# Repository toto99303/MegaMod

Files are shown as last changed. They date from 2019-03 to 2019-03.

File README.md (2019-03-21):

# MegaMod
These are the three versions of MegaMod PCB for Sega Genesis.
Created with Eagle PCB.

v1 - uses PIC16F630 (https://vmod.wordpress.com/megamod-v1-0/)  
v2 - uses Atmega328P with internal oscillator (https://vmod.wordpress.com/megamod-v2-0/)  
v3 - uses Atmega328P with internal oscillator + THS video amp (https://vmod.wordpress.com/megamod-v3-0/)

PIC code used in v1: https://github.com/sebknzl/saturnmod

The Arduino code for v2 and v3 was based on this project:
https://github.com/SukkoPera/MegaDrivePlusPlus

Due to some bugs related to the Atmega328P internal oscillator the Arduino code was never finished.

The audio part of the mod is based on the circuits posted in this forum by Ace (MegaAmp):
http://www.sega-16.com/forum/showthread.php?26568-Introducing-the-Mega-Amp-The-universal-Genesis-audio-circuit

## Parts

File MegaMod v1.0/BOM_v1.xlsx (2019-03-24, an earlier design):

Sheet: MegaMod v1
Discrete YM2612 - MD1 - All except VA7, MD2 - VA2, VA2.3 |  |  |  |  | ASIC YM3438, MD1 - VA7, MD2 - VA0, VA1, VA1.8, VA3
Name | Part | Count | Package | Remark | Name | Part | Count | Package | Remark
PCB | Board | 1 |  |  | PCB | Board | 1
U1 | TL074CD | 1 | SOIC127P600X175-14N |  | U1 | TL074CD | 1 | SOIC127P600X175-14N
U2 | PIC16F630-I/SL | 1 | SOIC127P600X175-14N |  | U2 | PIC16F630-I/SL | 1 | SOIC127P600X175-14N
S1 | DPDT Swtich | 1 | AYZ0202 |  | S1 | DPDT Swtich | 1 | AYZ0202
C1 | 100nF | 1 | 1210 |  | C1 | 100nF | 1 | 1210
C2 | 100uF | 1 | 1206 |  | C2 | 100uF | 1 | 1206
C3-C5 | 220uF | 3 | CAPAE830X650N |  | C3-C5 | 220uF | 3 | CAPAE830X650N
C6,C9 | 47pF | 2 | 1206 |  | C6,C9 | 47pF | 2 | 1206
C7-C8 | 270pF | 2 | 1206 |  | C7-C8 | 270pF | 2 | 1206
C10, C17 | 10uF | 2 | 1206 |  | C10, C17 | 10uF | 2 | 1206
C11-C16 | 1uF | 6 | 1206 |  | C11-C16 | 1uF | 6 | 1206
R1 -R2 | 220 | 2 | 1206 |  | R1 -R2 | 220 | 2 | 1206
R3 -R4 | 330 | 2 | 1206 |  | R3 -R4 | 330 | 2 | 1206
R5 - R6 | 160k | 2 | 1206 |  | R5 - R6 | 160k | 2 | 1206
R7 | 510 | 1 | 1206 |  | R7 | 510 | 1 | 1206
R8 | 750 | 1 | 1206 |  | R8 | 750 | 1 | 1206
R9, R22 | 2k2 | 0 | 1206 | Optional if fitting 2612 on asic board | R9, R22 | 2k2 | 0 | 1206
R10, R23 | 6k2 | 2 | 1206 |  | R10, R23 | 51k | 2 | 1206
R11, R13, R18, R20 | 75 | 4 | 1206 |  | R11, R13, R18, R20 | 75 | 4 | 1206
R12, R14, R19, R21 | 130k | 4 | 1206 |  | R12, R14, R19, R21 | 130k | 4 | 1206
R15 | 1k3 | 1 | 1206 | 330 for MD2 VA2, VA2.3 | R15 | 1k3 | 1 | 1206
R16 -R17 | 100k | 2 | 1206 |  | R16 -R17 | 100k | 2 | 1206
GOAC YM3438 - MD2 - VA4, MD3 - VA1,VA2
Name | Part | Count | Package | Remark
PCB | Board | 1
U1 | TL074CD | 1 | SOIC127P600X175-14N
U2 | PIC16F630-I/SL | 1 | SOIC127P600X175-14N
S1 | DPDT Swtich | 1 | AYZ0202
C1 | 100nF | 1 | 1210
C2 | 100uF | 1 | 1206
C3-C5 | 220uF | 3 | CAPAE830X650N
C6,C9 | 47pF | 2 | 1206
C7-C8 | 270pF | 2 | 1206
C10, C17 | 10uF | 2 | 1206
C11-C16 | 1uF | 6 | 1206
R1 -R2 | 220 | 2 | 1206
R3 -R4 | 330 | 2 | 1206
R5 - R6 | 160k | 2 | 1206
R7 | 510 | 1 | 1206
R8 | 750 | 1 | 1206
R9, R22 | 2k2 | 0 | 1206
R10, R23 | 39k | 2 | 1206
R11, R13, R18, R20 | 75 | 4 | 1206
R12, R14, R19, R21 | 130k | 4 | 1206
R15 | 2k2 | 1 | 1206
R16 -R17 | 75k | 2 | 1206

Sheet: V2 or V3
Mega Drive 1
 | Language | Video Mode
16F630 output leg | 9 | 12
Connects to | JP 1/2 | JP 3/4 | Sega CD BIOS
 |  |  |  | PIC 8 /Eprom 38 | PIC 10 /Eprom 39
EUR | 1 | 0 | EUR | 0 | 1
JPN | 0 | 1 | JPN | 1 | 0
USA | 1 | 1 | USA | 0 | 0
Final pinout | AVR pin | Arduino pin
RESET IN | PC3 | A3
RESET OUT | PC2 | A2
VIDEO MODE | PB0 | 8
LANGUAGE | PB4 | 12(MISO)
LED R | PB1 | 9
LED G | PB2 | 10
LED B | PB3 | 11
AUDIO MODE | PD7 | 7
CD EPROM pin 38 | PB6 | N/A
CD EPROM pin 39 | PB7 | N/A
PAD PIN 1 | PC0 | A0
PAD PIN 2 | PC1 | A1
PAD PIN 3 | PD3 | 3
PAD PIN 4 | PD4 | 4
PAD PIN 6 | PD5 | 5
PAD PIN 7 | PD2 | 2
PAD PIN 9 | PD6 | 6
INTERNAL LED | PB5 | 13

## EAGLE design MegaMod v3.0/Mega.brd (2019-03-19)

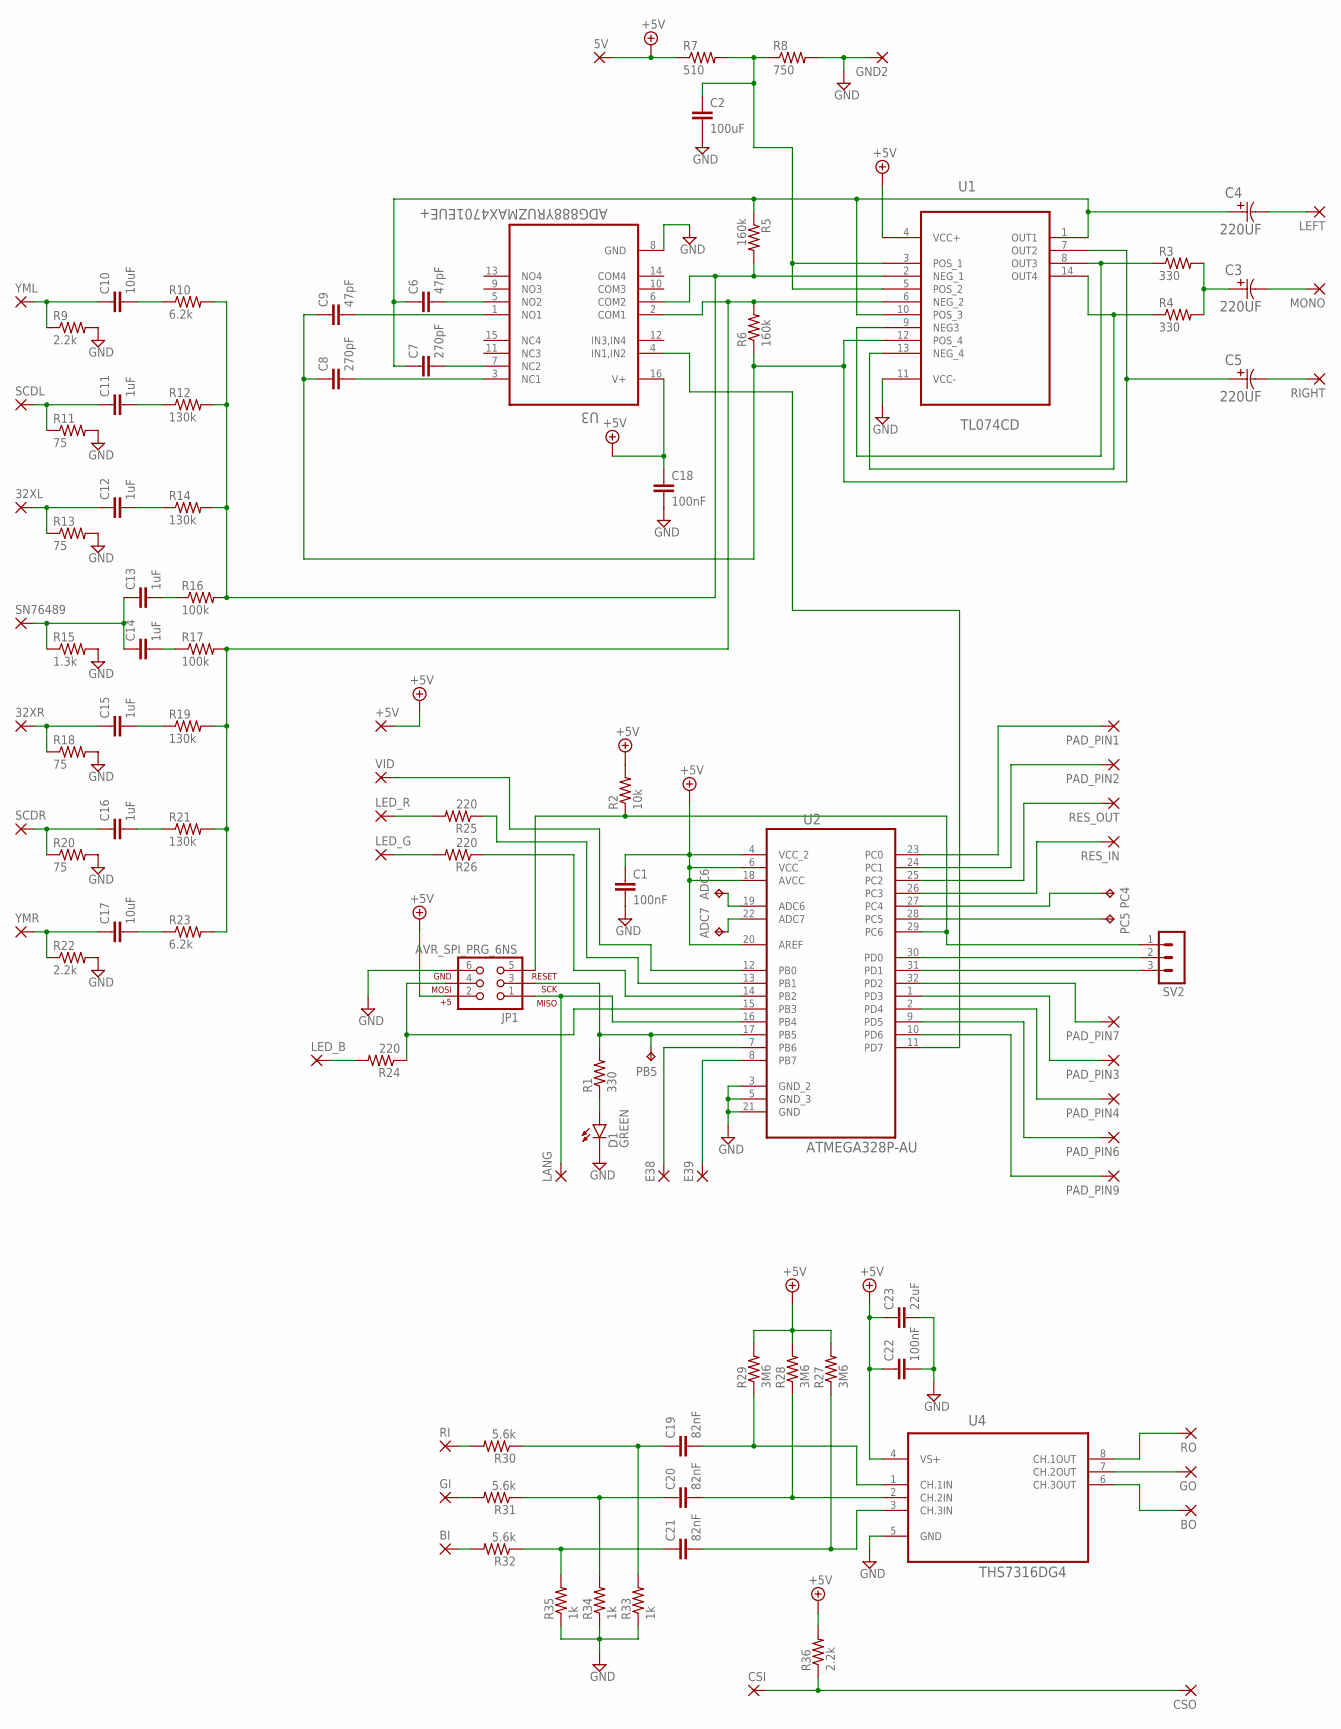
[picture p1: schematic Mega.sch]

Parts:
5V, 32XL, 32XR: SMD2; SMD1,27-2,54
+5V: SMD2; SMD1,27-2,54
ADC6, ADC7: TPB1,27; B1,27
BI: SMD2; SMD1,27-2,54
BO: SMD2; SMD1,27-2,54
C1, C18, C22: 100nF; 0805
C2: 100uF; 1206
C3, C4, C5: 220UF; CAPAE830X650N; TOLERANCE 20 %
C6, C9: 47pF; 0805
C7, C8: 270pF; 0805
C10, C17: 10uF; 0805
C11, C12, C13, C14, C15, C16: 1uF; 0805
C19, C20, C21: 82nF; 0805
C23: 22uF; 0805
CSI: SMD2; SMD1,27-2,54
CSO: SMD2; SMD1,27-2,54
D1: GREEN; LED-1206
E38, E39: SMD2; SMD1,27-2,54
GI: SMD2; SMD1,27-2,54
GND2: SMD2; SMD1,27-2,54
GO: SMD2; SMD1,27-2,54
JP1: AVR_SPI_PRG_6NS; 2X3-NS
LANG: SMD2; SMD1,27-2,54
LED_B: SMD2; SMD1,27-2,54
LED_G: SMD2; SMD1,27-2,54
LED_R: SMD2; SMD1,27-2,54
LEFT: SMD2; SMD1,27-2,54
MONO: SMD2; SMD1,27-2,54
PAD_PIN1, PAD_PIN2, PAD_PIN3, PAD_PIN4, PAD_PIN6, PAD_PIN7, PAD_PIN9: SMD2; SMD1,27-2,54
PB5: TPB1,27; B1,27
PC4, PC5: TPB1,27; B1,27
R1, R3, R4: 330; 0805
R2: 10k; 0805
R5, R6: 160k; 0805
R7: 510; 0805
R8: 750; 0805
R9, R22, R36: 2.2k; 0805
R10, R23: 6.2k; 0805
R11, R13, R18, R20: 75; 0805
R12, R14, R19, R21: 130k; 0805
R15: 1.3k; 0805
R16, R17: 100k; 0805
R24, R25, R26: 220; 0805
R27, R28, R29: 3M6; 0805
R30, R31, R32: 5.6k; 0805
R33, R34, R35: 1k; 0805
RES_IN: SMD2; SMD1,27-2,54
RES_OUT: SMD2; SMD1,27-2,54
RI: SMD2; SMD1,27-2,54
RIGHT: SMD2; SMD1,27-2,54
RO: SMD2; SMD1,27-2,54
SCDL: SMD2; SMD1,27-2,54
SCDR: SMD2; SMD1,27-2,54
SN76489: SMD2; SMD1,27-2,54
SV2: MA03-1
U1: TL074CD; SOIC127P600X175-14N
U2: ATMEGA328P-AU; QFP80P900X900X120-32N
U3: ADG888YRUZMAX4701EUE+; SOP65P640X120-16N
U4: THS7316DG4; SOIC127P600X175-8N
VID: SMD2; SMD1,27-2,54
YML: SMD2; SMD1,27-2,54
YMR: SMD2; SMD1,27-2,54

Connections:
+5V: 5V.1, +5V.1, C1.1, C18.1, C22.1, C23.1, JP1.2, R2.2, R7.1, R27.2, R28.2, R29.2, R36.2, U1.4 (VCC+), U2.4 (VCC_2), U2.6 (VCC), U2.18 (AVCC), U2.20 (AREF), U3.16 (V+), U4.4 (VS+)
GND: C1.2, C2.2, C18.2, C22.2, C23.2, D1.C, GND2.1, JP1.6, R8.2, R9.2, R11.2, R13.2, R15.2, R18.2, R20.2, R22.2, R33.1, R34.1, R35.1, U1.11 (VCC-), U2.3 (GND_2), U2.5 (GND_3), U2.21 (GND), U3.8 (GND), U4.5 (GND)
unnamed: D1.A, R1.1
unnamed: JP1.3, PB5.TP, R1.2, U2.17 (PB5)
unnamed: JP1.5, R2.1, SV2.1, U2.29 (PC6)
unnamed: JP1.1, LANG.1, U2.16 (PB4)
unnamed: JP1.4, R24.1, U2.15 (PB3)
unnamed: LED_R.1, R25.2
unnamed: LED_G.1, R26.2
unnamed: R3.1, U1.8 (OUT3), U1.9 (NEG3)
unnamed: PC4.TP, U2.27 (PC4)
unnamed: PC5.TP, U2.28 (PC5)
unnamed: R4.1, U1.13 (NEG_4), U1.14 (OUT4)
unnamed: C3.1, R3.2, R4.2
unnamed: C3.2, MONO.1
unnamed: C4.2, LEFT.1
unnamed: RES_IN.1, U2.26 (PC3)
unnamed: C4.1, C6.1, C7.1, R5.1, U1.1 (OUT1), U1.10 (POS_3)
unnamed: C5.1, C8.1, C9.1, R6.1, U1.7 (OUT2), U1.12 (POS_4)
unnamed: C5.2, RIGHT.1
unnamed: R6.2, R17.2, R19.2, R21.2, R23.2, U1.6 (NEG_2), U3.2 (COM1)
unnamed: C6.2, U3.5 (NO2)
unnamed: C8.2, U3.3 (NC1)
unnamed: C7.2, U3.7 (NC2)
unnamed: C9.2, U3.1 (NO1)
unnamed: C10.1, R9.1, YML.1
unnamed: C2.1, R7.2, R8.1, U1.3 (POS_1), U1.5 (POS_2)
unnamed: C10.2, R10.1
unnamed: C11.1, R11.1, SCDL.1
unnamed: C11.2, R12.1
unnamed: 32XL.1, C12.1, R13.1
unnamed: C12.2, R14.1
unnamed: C13.1, C14.1, R15.1, SN76489.1
unnamed: C13.2, R16.1
unnamed: C17.1, R22.1, YMR.1
unnamed: C14.2, R17.1
unnamed: 32XR.1, C15.1, R18.1
unnamed: C15.2, R19.1
unnamed: C16.1, R20.1, SCDR.1
unnamed: C16.2, R21.1
unnamed: C17.2, R23.1
unnamed: R5.2, R10.2, R12.2, R14.2, R16.2, U1.2 (NEG_1), U3.6 (COM2)
unnamed: PAD_PIN2.1, U2.24 (PC1)
unnamed: SV2.3, U2.31 (PD1)
unnamed: SV2.2, U2.30 (PD0)
unnamed: PAD_PIN7.1, U2.32 (PD2)
unnamed: PAD_PIN3.1, U2.1 (PD3)
unnamed: PAD_PIN4.1, U2.2 (PD4)
unnamed: PAD_PIN6.1, U2.9 (PD5)
unnamed: PAD_PIN9.1, U2.10 (PD6)
unnamed: LED_B.1, R24.2
unnamed: R26.1, U2.14 (PB2)
unnamed: R25.1, U2.13 (PB1)
unnamed: U2.12 (PB0), VID.1
unnamed: E38.1, U2.7 (PB6)
unnamed: E39.1, U2.8 (PB7)
unnamed: U2.11 (PD7), U3.4 (IN1,IN2)
unnamed: C20.2, R28.1, U4.2 (CH.2IN)
unnamed: C19.2, R29.1, U4.1 (CH.1IN)
unnamed: C21.2, R27.1, U4.3 (CH.3IN)
unnamed: C19.1, R30.1, R33.2
unnamed: C20.1, R31.1, R34.2
unnamed: C21.1, R32.1, R35.2
unnamed: BI.1, R32.2
unnamed: GI.1, R31.2
unnamed: R30.2, RI.1
unnamed: CSI.1, CSO.1, R36.1
unnamed: GO.1, U4.7 (CH.2OUT)
unnamed: RO.1, U4.8 (CH.1OUT)
unnamed: BO.1, U4.6 (CH.3OUT)
unnamed: RES_OUT.1, U2.25 (PC2)
unnamed: PAD_PIN1.1, U2.23 (PC0)
unnamed: ADC7.TP, U2.22 (ADC7)
unnamed: ADC6.TP, U2.19 (ADC6)

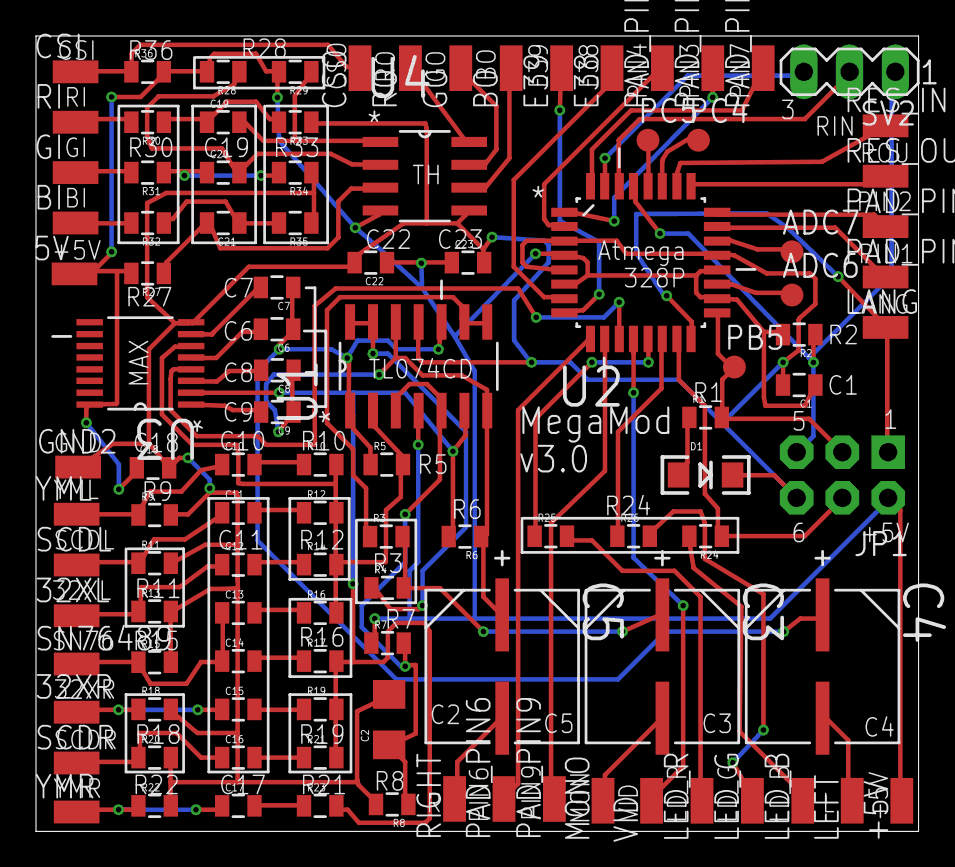
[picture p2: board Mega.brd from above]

Board: 2 copper layers, 49.0 x 44.2 mm, 108 parts (0 on the bottom side), 74 nets.

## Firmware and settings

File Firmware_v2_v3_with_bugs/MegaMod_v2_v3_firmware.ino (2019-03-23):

#include <Arduino.h>

volatile static byte pad_status;
         int i = 0;

#define ARDUINO328

#define RESET_IN_PIN A3
#define RESET_OUT_PIN A2
#define VIDEOMODE_PIN 8 //A4
#define LANGUAGE_PIN MISO //A5
#define MODE_LED_R_PIN 9
#define MODE_LED_G_PIN 10
#define MODE_LED_B_PIN 11
#define AUDIO_MODE_PIN 7
#define PAD_LED_PIN LED_BUILTIN
#define ENABLE_SERIAL_DEBUG
//#define FORCE_RESET_ACTIVE_LEVEL 0


enum PadButton {
  MD_BTN_START = 1 << 7,
  MD_BTN_A =     1 << 6,
  MD_BTN_C =     1 << 5,
  MD_BTN_B =     1 << 4,
  MD_BTN_RIGHT = 1 << 3,
  MD_BTN_LEFT =  1 << 2,
  MD_BTN_DOWN =  1 << 1,
  MD_BTN_UP =    1 << 0
};

/* Button combo that enables the other combos
 *
 * Note: That vertical bar ("pipe") means that the buttons must be pressed
 *       together.
 */

#define TRIGGER_COMBO (MD_BTN_START | MD_BTN_B)
//#define TRIGGER_COMBO (MD_BTN_START)

#define TRIGGER_COMBO2 (MD_BTN_START | MD_BTN_A) //additional combo

/* Button combos to perform other actions. These are to be considered in
 * addition to TRIGGER_COMBO.
 *
 * Note that we cannot detect certain buttons on some platforms
 */
#define RESET_COMBO (MD_BTN_A)



#if defined ARDUINO328

  #define AUDIO_COMBO MD_BTN_UP
  #define EUR_COMBO MD_BTN_DOWN
  #define USA_COMBO MD_BTN_RIGHT
  #define JAP_COMBO MD_BTN_LEFT
  #define COMBO_50 MD_BTN_LEFT
  #define COMBO_60 MD_BTN_RIGHT
#endif

#define MODE_ROM_OFFSET 42
#define AUDIO_ROM_OFFSET 50

// Time to wait after mode change before saving the new mode (milliseconds)
#define MODE_SAVE_DELAY 2000L

// Force the reset line level when active. Undefine to enable auto-detection.
//#define FORCE_RESET_ACTIVE_LEVEL LOW

/* Colors to use to indicate the video mode, in 8-bit RGB componentes. You can
 * use any value here if your led is connected to PWM-capable pins, otherwise
 * values specified here will be interpreted as either fully off (if 0) or fully
 * on (if anything else).
 *
 * Note that using PWM-values here sometimes causes unpredictable problems. This
 * happened to me on an ATtiny861, and it's probably due to how pins and timers
 * interact. It seems to work fine on a full Arduino, but unless you really want
 * weird colors, use only 0x00 and 0xFF.
 */

#define MODE_LED_EUR_COLOR {0x00, 0xFF, 0x00}  // Green
#define MODE_LED_USA_COLOR {0x00, 0x00, 0xFF}  // Blue
#define MODE_LED_JAP_COLOR {0xFF, 0x00, 0x00}  // Red
#define MODE_VID_MOD_COLOR {0xFF, 0xFF, 0x00}  // Yellow


// Define this if your led is common-anode, comment out for common-cathode
#define MODE_LED_COMMON_ANODE



/* Presses of the reset button longer than this amount of milliseconds will
 * switch to the next mode, shorter presses will reset the console.
 */
#define LONGPRESS_LEN 700

// Debounce duration for the reset button
#define DEBOUNCE_MS 20

// Duration of the reset pulse (milliseconds)
#define RESET_LEN 350

/*******************************************************************************
 * END OF SETTINGS
 ******************************************************************************/


#ifdef ENABLE_SERIAL_DEBUG
  #define debug(...) Serial.print (__VA_ARGS__)
  #define debugln(...) Serial.println (__VA_ARGS__)
#else
  #define debug(...)
  #define debugln(...)
#endif

#ifdef MODE_ROM_OFFSET
  #include <EEPROM.h>
#endif

enum VideoMode {
  EUR,
  USA,
  JAP,
  MODES_NO, // End of modes
  VID50,
  VID60
};

// This will be handy
#if (defined MODE_LED_R_PIN || defined MODE_LED_G_PIN || defined MODE_LED_B_PIN)
  #define ENABLE_MODE_LED_RGB

byte mode_led_colors[][MODES_NO] = {
  MODE_LED_EUR_COLOR,
  MODE_LED_USA_COLOR,
  MODE_LED_JAP_COLOR,
  MODE_VID_MOD_COLOR
};
#endif

void set_mode (VideoMode m);

VideoMode current_mode;
bool audio_mode;
long mode_last_changed_time;
long audio_mode_last_changed_time;

// Reset level when NOT ACTIVE
byte reset_inactive_level;

void save_mode () {
#ifdef MODE_ROM_OFFSET
  if (mode_last_changed_time > 0 && millis () - mode_last_changed_time >= MODE_SAVE_DELAY) {
    debug ("Saving video mode to EEPROM: ");
    debugln (current_mode);
    byte saved_mode = EEPROM.read (MODE_ROM_OFFSET);
    if (current_mode != saved_mode) {
      EEPROM.write (MODE_ROM_OFFSET, static_cast<byte> (current_mode));
    } else {
      debugln ("Mode unchanged, not saving");
    }
    mode_last_changed_time = 0;    // Don't save again

    // Blink led to tell the user that mode was saved
	set_RGB_leds(0, 0, 0);

    // Keep off for a bit
    delay (200);
  
    // Turn led back on
    update_mode_leds ();

  }
#endif  // MODE_ROM_OFFSET
}

void save_audio() {
#ifdef AUDIO_ROM_OFFSET
	if (audio_mode_last_changed_time > 0 && millis() - audio_mode_last_changed_time >= MODE_SAVE_DELAY) {
		debug("Saving audio mode to EEPROM: ");
		debugln(audio_mode);
		EEPROM.write(AUDIO_ROM_OFFSET, static_cast<byte> (audio_mode));

		audio_mode_last_changed_time = 0;    // Don't save again

		// Blink led to tell the user that mode was saved
		set_RGB_leds(0, 0, 0);

		// Keep off for a bit
		delay(200);

		// Turn led back on
		update_mode_leds();

}
#endif  // AUDIO_ROM_OFFSET
}


void change_mode (int increment) {
  // This also loops in [0, MODES_NO) backwards
  VideoMode new_mode = static_cast<VideoMode> ((current_mode + increment + MODES_NO) % MODES_NO);
  set_mode (new_mode);
}

void next_mode () {
  change_mode (+1);
}

void prev_mode () {
  change_mode (-1);
}

void set_RGB_leds(byte R, byte G, byte B) {

#ifdef MODE_LED_COMMON_ANODE
	R = 255 - R;
	G = 255 - G;
	B = 255 - B;
#endif
	analogWrite(MODE_LED_R_PIN, R);
	analogWrite(MODE_LED_G_PIN, G);
	analogWrite(MODE_LED_B_PIN, B);
}

void update_mode_leds () {
#ifdef ENABLE_MODE_LED_RGB
  byte *colors = mode_led_colors[current_mode];
  set_RGB_leds(colors[0], colors[1], colors[2]);

#endif  // ENABLE_MODE_LED_RGB
}



void flash_vid_mode_leds(bool mode, int b_delay) {

	byte *colors = mode_led_colors[3];

	if (mode == 0) //50Hz
	{
		set_RGB_leds(colors[0], colors[1], colors[2]);
		delay(b_delay);
		set_RGB_leds(0, 0, 0);
		delay(b_delay);

		set_RGB_leds(colors[0], colors[1], colors[2]);
		delay(b_delay);
		set_RGB_leds(0, 0, 0);
		delay(b_delay);

		set_RGB_leds(colors[0], colors[1], colors[2]);
		delay(b_delay);
		set_RGB_leds(0, 0, 0);
		delay(b_delay);

		set_RGB_leds(colors[0], colors[1], colors[2]);
		delay(b_delay);
		set_RGB_leds(0, 0, 0);
		delay(b_delay);
	}
	else //60Hz
	{
		set_RGB_leds(colors[0], colors[1], colors[2]);
		delay(b_delay);
		set_RGB_leds(0, 0, 0);
		delay(b_delay);

		set_RGB_leds(colors[0], colors[1], colors[2]);
		delay(b_delay);
		set_RGB_leds(0, 0, 0);
		delay(b_delay);

		set_RGB_leds(colors[0], colors[1], colors[2]);
		delay(b_delay);
		set_RGB_leds(0, 0, 0);
		delay(b_delay);

		set_RGB_leds(colors[0], colors[1], colors[2]);
		delay(b_delay);
		set_RGB_leds(0, 0, 0);
		delay(b_delay);

    set_RGB_leds(colors[0], colors[1], colors[2]);
    delay(b_delay);
    set_RGB_leds(0, 0, 0);
    delay(b_delay);

    set_RGB_leds(colors[0], colors[1], colors[2]);
    delay(b_delay);
    set_RGB_leds(0, 0, 0);
    delay(b_delay);
	}

	update_mode_leds();
	
}

void set_mode (VideoMode m) {
	if (m == VID50) {
		digitalWrite(VIDEOMODE_PIN, LOW);
		flash_vid_mode_leds(0,100);
	} else if (m == VID60) {
    digitalWrite(VIDEOMODE_PIN, HIGH);
    flash_vid_mode_leds(1,50);
  }
	else {
		switch (m) {
		default:
		case EUR:
			digitalWrite(VIDEOMODE_PIN, LOW);    // PAL 50Hz
			digitalWrite(LANGUAGE_PIN, HIGH);    // ENG

			PORTB &= ~(1 << PORTB6); //low Sega CD BIOS EPROM pin 38
			PORTB |= (1 << PORTB7); //high Sega CD BIOS EPROM pin 39
			break;
		case USA:
			digitalWrite(VIDEOMODE_PIN, HIGH);   // NTSC 60Hz
			digitalWrite(LANGUAGE_PIN, HIGH);    // ENG

			PORTB &= ~((1 << PORTB6) | (1 << PORTB7)); //both low Sega CD BIOS EPROM pins 38 and 39
			break;
		case JAP:
			digitalWrite(VIDEOMODE_PIN, HIGH);   // NTSC 60Hz
			digitalWrite(LANGUAGE_PIN, LOW);     // JAP

			PORTB |= (1 << PORTB6); //high Sega CD BIOS EPROM pin 38
			PORTB &= ~(1 << PORTB7); //low Sega CD BIOS EPROM pin 39
			break;
		}

		current_mode = m;
		update_mode_leds();

		mode_last_changed_time = millis();
	}
}

void set_audio_mode(bool m) {
	digitalWrite(AUDIO_MODE_PIN, m); 
	audio_mode = m;
	update_mode_leds();

	audio_mode_last_changed_time = millis();
}


void handle_reset_button () {
  static byte debounce_level = LOW;
  static bool reset_pressed_before = false;
  static long last_int = 0, reset_press_start = 0;
  static unsigned int hold_cycles = 0;

  byte reset_level = digitalRead (RESET_IN_PIN);
  if (reset_level != debounce_level) {
    // Reset debouncing timer
    last_int = millis ();
    debounce_level = reset_level;
  } else if (millis () - last_int > DEBOUNCE_MS) {
    // OK, button is stable, see if it has changed
    if (reset_level != reset_inactive_level && !reset_pressed_before) {
      // Button just pressed
      reset_press_start = millis ();
      hold_cycles = 0;
    }
    else if (reset_level == reset_inactive_level && reset_pressed_before) {
      // Button released
      if (hold_cycles == 0) {
        debugln ("Reset button pushed for a short time");
        reset_console ();
		}

    } else {
      // Button has not just been pressed/released
      if (reset_level != reset_inactive_level && millis () % reset_press_start >= LONGPRESS_LEN * (hold_cycles + 1)) {
        // Reset has been hold for a while
        debugln ("Reset button hold");
        ++hold_cycles;
        next_mode ();
      }

    }

    reset_pressed_before = (reset_level != reset_inactive_level);
  }
}

void reset_console () {
  debugln ("Resetting console");

  digitalWrite (RESET_OUT_PIN, !reset_inactive_level);
  delay (RESET_LEN);
  digitalWrite (RESET_OUT_PIN, reset_inactive_level);
}


void setup () {

  OSCCAL=134; //manual oscillator calibration for serial debug

#ifdef ENABLE_SERIAL_DEBUG
  Serial.begin (9600);
#endif

DDRB |= (1 << DDB6) | (1 << DDB7); //enable CD bios outputs

  debugln ("Starting up...");

/* Rant: As per D4s's installation schematics out there (which we use too), it
 * seems that on consoles with an active low reset signal, the Reset In input
 * is taken before the pull-up resistor, while on consoles with active-high
 * reset it is taken AFTER the pull-down resistor. This means that detecting
 * the reset level by sampling the same line on both consoles is tricky, as in
 * both cases one of the Reset In/Out signals is left floating :(. The
 * following should work reliably, but we allow for a way to force the reset
 * line level.
 */
#ifndef FORCE_RESET_ACTIVE_LEVEL
  // Let things settle down and then sample the reset line
  delay (100);
  pinMode (RESET_IN_PIN, INPUT_PULLUP);
  reset_inactive_level = digitalRead (RESET_IN_PIN);
  debug ("Reset line is ");
  debug (reset_inactive_level ? "HIGH" : "LOW");
  debugln (" at startup");
#else
  reset_inactive_level = !FORCE_RESET_ACTIVE_LEVEL;
  debug ("Reset line is forced to active-");
  debugln (FORCE_RESET_ACTIVE_LEVEL ? "HIGH" : "LOW");
#endif

  if (reset_inactive_level == LOW) {
    // No need for pull-up
    pinMode (RESET_IN_PIN, INPUT);
  } else {
    pinMode (RESET_IN_PIN, INPUT_PULLUP);
  }

  // Enable reset
  pinMode (RESET_OUT_PIN, OUTPUT);
  digitalWrite (RESET_OUT_PIN, !reset_inactive_level);

  // Setup leds
#ifdef MODE_LED_R_PIN
  pinMode (MODE_LED_R_PIN, OUTPUT);
#endif

#ifdef MODE_LED_G_PIN
  pinMode (MODE_LED_G_PIN, OUTPUT);
#endif

#ifdef MODE_LED_B_PIN
  pinMode (MODE_LED_B_PIN, OUTPUT);
#endif

#ifdef PAD_LED_PIN
  pinMode (PAD_LED_PIN, OUTPUT);
#endif

#ifdef AUDIO_MODE_PIN
  pinMode(AUDIO_MODE_PIN, OUTPUT);
#endif


  // Init video mode
  pinMode (VIDEOMODE_PIN, OUTPUT);
  pinMode (LANGUAGE_PIN, OUTPUT);
  current_mode = EUR;
  audio_mode = 1;

#ifdef MODE_ROM_OFFSET
  byte tmp = EEPROM.read (MODE_ROM_OFFSET);
  debug ("Loaded video mode from EEPROM: ");
  debugln (tmp);
  if (tmp < MODES_NO) {
    // Palette EEPROM value is good
    current_mode = static_cast<VideoMode> (tmp);
  }
#endif

#ifdef AUDIO_ROM_OFFSET
  byte tmp2 = EEPROM.read(AUDIO_ROM_OFFSET);
  debug("Loaded audio mode from EEPROM: ");
  debugln(tmp2);
  audio_mode = static_cast<bool> (tmp2);
#endif

  set_mode (current_mode);
  set_audio_mode(audio_mode);
  mode_last_changed_time = 0; 
  audio_mode_last_changed_time = 0;  // No need to save what we just loaded

  // Prepare to read pad
  setup_pad ();

  // Finally release the reset line
  digitalWrite (RESET_OUT_PIN, reset_inactive_level);
}

void setup_pad () {
  // Set port directions
#if defined ARDUINO328
  DDRC &= ~((1 << DDC1) | (1 << DDC0));
  DDRD &= ~((1 << DDD6) | (1 << DDD5) | (1 << DDD4) | (1 << DDD3) | (1 << DDD2));
  attachInterrupt(digitalPinToInterrupt(2), select_low, FALLING);
#endif
}

/******************************************************************************/
/*
 * The basic idea here is to make up a byte where each bit represents the state
 * of a button, where 1 means pressed, for commodity's sake. The bit-button
 * mapping is defined in the PadButton enum above.
 *
 * To get consistent readings, we should really read all of the pad pins at
 * once, since some of them must be interpreted according to the value of the
 * SELECT signal. In order to do this we could connect all pins to a single port
 * of our MCU, but this is a luxury we cannot often afford, for various reasons.
 * Luckily, the UP and DOWN signals do not depend upon the SELECT pins, so we
 * can read them anytime, and this often takes us out of trouble.
 *
 * Note that printing readings through serial slows down the code so much that
 * it misses most of the readings with SELECT low!
 */


void select_low() {
	// Select is low, we have Start & A
	byte portdd = PIND;
	pad_status = (pad_status & 0x3F) | ((~portdd & ((1 << PD6) | (1 << PD5))) << 1);
 // delayMicroseconds(15000);
}

inline byte read_pad () {

    // Update UP and DOWN, which are always valid and on PORTC alone
    pad_status = (pad_status & 0xFC) | (~PINC & ((1 << PC1) | (1 << PC0)));

    byte portd = PIND;
    // Select is high, we have Right, Left, C & B
    pad_status = (pad_status & 0xC3) | ((~portd & ((1 << PIND6) | (1 << PD5) | (1 << PD4) | (1 << PD3))) >> 1);
    
    return pad_status;
}

#define IGNORE_COMBO_MS LONGPRESS_LEN

#define MIN_START_BUTTON_PRESS 3 // minimum Start button detections (filter junk), default is 50 times

void handle_pad() {
	static long last_combo_time = 0;

	read_pad();

#ifdef PAD_LED_PIN
	digitalWrite(PAD_LED_PIN, pad_status);
#endif



#if 1
	if (pad_status != 0) {
		//Serial.print("Pad status = ");
		Serial.println(pad_status, BIN);
}
#endif

    // Filtering start button false triggers to avoid combos.
//    if ((pad_status >> 7) & 0x01) {
//    i++;
//    } else i = 0;
//
//    if (i < MIN_START_BUTTON_PRESS) {
//    pad_status &= ~(1 << 7);     
//    } else i = 0;
   
  if ((pad_status & TRIGGER_COMBO) == TRIGGER_COMBO && millis () - last_combo_time > IGNORE_COMBO_MS) {
    Serial.print("combo status = ");
    Serial.println(pad_status, BIN);
    if ((pad_status & RESET_COMBO) == RESET_COMBO) {
      debugln ("Reset combo detected");
     // reset_console ();
      pad_status = 0;     // Avoid continuous reset (pad_status might keep the last value during reset!)
      last_combo_time = millis ();
      Serial.print("reset status = ");
      Serial.println(pad_status, BIN);
#ifdef EUR_COMBO
    } else if ((pad_status & EUR_COMBO) == EUR_COMBO) {
      debugln ("EUR mode combo detected");
      set_mode (EUR);
      last_combo_time = millis ();
#endif
#ifdef USA_COMBO
    } else if ((pad_status & USA_COMBO) == USA_COMBO) {
      debugln ("USA mode combo detected");
      set_mode (USA);
      last_combo_time = millis ();
#endif
#ifdef JAP_COMBO
    } else if ((pad_status & JAP_COMBO) == JAP_COMBO) {
      debugln ("JAP mode combo detected");
      set_mode (JAP);
      last_combo_time = millis ();
#endif
#ifdef NEXT_MODE_COMBO
    } else if ((pad_status & NEXT_MODE_COMBO) == NEXT_MODE_COMBO) {
      debugln ("Next mode combo detected");
      next_mode ();
      last_combo_time = millis ();
#endif
#ifdef PREV_MODE_COMBO
    } else if ((pad_status & PREV_MODE_COMBO) == PREV_MODE_COMBO) {
      debugln ("Previous mode combo detected");
      prev_mode ();
      last_combo_time = millis ();
#endif
#ifdef AUDIO_COMBO
    } else if ((pad_status & AUDIO_COMBO) == AUDIO_COMBO) {
      debugln ("Audio combo detected");
	  set_audio_mode(!audio_mode);
      last_combo_time = millis ();
#endif
    }
  }

  if ((pad_status & TRIGGER_COMBO2) == TRIGGER_COMBO2 && millis() - last_combo_time > IGNORE_COMBO_MS) {
	  if ((pad_status & COMBO_50) == COMBO_50) {
		  debugln("50Hz mode combo detected");
		  set_mode(VID50);
		  last_combo_time = millis();
	  } else if ((pad_status & COMBO_60) == COMBO_60) {
      debugln("60Hz mode combo detected");
      set_mode(VID60);
      last_combo_time = millis();
	  }
   
  }
}

void loop () {
  handle_reset_button ();
  handle_pad ();
  save_mode ();
  save_audio ();
}

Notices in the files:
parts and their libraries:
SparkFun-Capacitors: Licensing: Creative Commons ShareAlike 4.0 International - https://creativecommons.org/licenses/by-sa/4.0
